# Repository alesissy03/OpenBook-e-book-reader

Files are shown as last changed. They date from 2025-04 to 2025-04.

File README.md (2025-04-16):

# OpenBook-e-book-reader



# Project Structure
```
OpenBook E-Reader
├── Hardware
│ ├── E-Reader.sch
│ └── E-Reader.brd
├── Manufacturing
│ ├── gerbers.zip
│ ├── bom.csv
│ └── pap.csv
├── Mechanical
│ ├── E-Reader.zip # STEP model archive
│ ├── E-Reader.f3z
│ └── OpenBook Enclosure.f3d # Enclosure model
├── Images
│ ├── 3d.png
│ ├── Schematic.png
│ ├── Board.png
│ └── Board_in_box.png
├── LICENSE # Apache 2.0
└── README.md
```

# Bill of Materials

## Component List

| Name | Description | Value | Quantity | Link to buy| Datasheet |
|---|---|---|---|---|---|
| 744043680 | IND_4828-WE-TPC_WRE | 68uH | 1 | https://mou.sr/42yVhMe | https://www.we-online.com/components/products/datasheet/744043680.pdf |
| 112A-TAAR-RO3_ATTEND | Micro SD Card Socket, Push-Push Type, Top Mount, SMT, H = 1.83mm | 10u | 1 | https://www.attend.com.tw/en/product.php?act=view&id=253# | https://www.attend.com.tw/data/download/file/112A-TAAR-R03_Spec.pdf |
| BD5229G-TR | Voltage Detector with Adjustable Delay Time (CMOS) | | 1 | https://mou.sr/421TSO9 | https://fscdn.rohm.com/en/products/databook/datasheet/ic/power/voltage_detector/bd52xxg-e.pdf |
| BUTTON_CUSYOMV1 | Momentary Switch (Pushbutton) – SPST – SMD, 4.6 x 2.8mm | | 3 | https://mou.sr/41Yc6zX | https://4donline.ihs.com/images/VipMasterIC/IC/PANA/PANA-S-A0000771493/PANA-S-A0000771493-1.pdf? hkey=CECEF36DEECDED6468708AAF2E19C0C6 |
| CPH3225A | Capacitor 0.011F 3.3V 1210 Flat | | 1 | https://mou.sr/42aoXOc | https://ro.mouser.com/datasheet/2/360/Seiko_Instruments_MicroBattery_E_20230330_2024Jan_-3561061.pdf |
| DS3231SN# | Real Time Clock Serial 16-Pin SOIC W T/R | | 1 | https://mou.sr/4ll9PXb | https://ro.mouser.com/datasheet/2/609/DS3231-3421123.pdf |
| EAGLE-LTSPICE_CC0402 | Capacitor | 100nF | 8 | https://mou.sr/42aprE0 | https://www.mouser.com/catalog/specsheets/Kemet_2-4-2024_KEM_F3140_R41D_Y2_300%20(draft3)%20(3).pdf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. |
| EAGLE-LTSPICE_CC0402 | Capacitor | 4.7uF | 5 | https://mou.sr/44lcHNw | https://ro.mouser.com/datasheet/2/40/AutoMLCCKAM-3216307.pdf |
| EAGLE-LTSPICE_CC0402 | Capacitor | 10uF | 1 | https://mou.sr/3G8LNhS | https://ro.mouser.com/datasheet/2/40/cx5r_KGM-3223198.pdf |
| EAGLE-LTSPICE_CC0402 | Capacitor | 1uF/50V | 9 | https://mou.sr/3YwHHGK | https://ro.mouser.com/datasheet/2/447/upy_gphc_x5r_4v_to_50v-3461255.pdf |
| EAGLE-LTSPICE_CC0402 | Capacitor | 0.1uF/50V | 1 | https://mou.sr/3RC3wkl | https://product.tdk.com/system/files/dam/doc/product/capacitor/ceramic/mlcc/catalog/mlcc_commercial_midvoltage_en.pdf |
| EAGLE-LTSPICE_CC0402 | Capacitor | 1nF | 1 | https://mou.sr/3YwHHGK | https://ro.mouser.com/datasheet/2/447/upy_gphc_x5r_4v_to_50v-3461255.pdf |
| ESP32_WROVER_BME680_BME680 | Integrated Environmental Unit (BME680) | | 1 | https://mou.sr/42kgEzJ | https://ro.mouser.com/datasheet/2/783/BST_BME680_DS001-1509608.pdf |
| ESP32_WROVER_AVX--- | Schotty Barrier Rectifier Diode | | 1 | |
| ESP32_WROVER_RR0402 | Resistor | 10k | 15 | https://mou.sr/4i5Vvim | https://www.vishay.com/docs/53046/pfrr.pdf |
| ESP32_WROVER_RR0402 | Resistor | 2.2 | 1 | https://mou.sr/4i9Xsun | https://www.vishay.com/docs/53046/pfrr.pdf |
| ESP32_WROVER_RR0402 | Resistor | 0.47 | 1 | https://mou.sr/4i9XAKn | https://www.vishay.com/docs/53046/pfrr.pdf |
| ESP32_WROVER_RR0402 | Resistor | 200 | 1 | https://mou.sr/4i9XAKn | https://www.vishay.com/docs/53046/pfrr.pdf |
| ESP32_WROVER_RR0402 | Resistor | 2k | 1 | https://mou.sr/4jeq8Do | https://www.vishay.com/docs/53046/pfrr.pdf |
| ESP32_WROVER_RR0402 | Resistor | 15 | 1 | https://mou.sr/4i5Vvim | https://www.vishay.com/docs/53046/pfrr.pdf |
| ESP32_WROVER_RR0402 | Resistor | 5k1 | 2 | https://mou.sr/4jeq8Do | https://www.vishay.com/docs/53046/pfrr.pdf |
| ESP32_WROVER_RR0402 | Resistor | 100k | 1 | https://mou.sr/4jeq8Do | https://www.vishay.com/docs/53046/pfrr.pdf |
| ESP32_WROVER_SPARKFUN- | P-channel MOSFETs | | 2 | https://mou.sr/42jyNxv | https://ro.mouser.com/datasheet/2/268/MCP73831_Family_Data_Sheet_DS20001984H-3441711.pdf |
| ESP32_WROVER_SPARKFUN-IC- | MCP73831T Li-Ion, Li-Pol Controller | | 1 | https://mou.sr/42jyNxv | https://ro.mouser.com/datasheet/2/268/MCP73831_Family_Data_Sheet_DS20001984H-3441711.pdf |
| ESP32C6_VARISTORCN1812 | Varistor | | 1 | https://mou.sr/3RnbVYV | https://www.tdk-electronics.tdk.com/inf/75/db/CTVS_14/Surge_protection_series.pdf |
| ESP32-C6-WROOM-1-N8 | | | 1 | https://mou.sr/42swLfH | https://ro.mouser.com/datasheet/2/891/Espressif_ESP32_C6_WROOM_1__Datasheet_V0_1_PRELIMI-3239987.pdf |
| FH34SRJ-24S-0.5SH_99_ | 24-pos FFC/FPC Connector, Right Angle | | 1 |  https://mou.sr/43Cr53R | https://ro.mouser.com/datasheet/2/185/FH34SRJ_24S_0_5SH_99__CL0580_1255_6_99_2DDrawing_0-1615044.pdf |
| MAX17048G+T10 | Fuel Gauge | | 1 | https://mou.sr/3FWR5wY | https://ro.mouser.com/datasheet/2/609/MAX17048_MAX17049-3469099.pdf |
| MBR0530 | Diode, Schottky, 0.5A, 30V, SOD-123 | | 2 | https://mou.sr/4jmza1b | https://www.onsemi.com/download/data-sheet/pdf/mbr0530t1-d.pdf |
| PGB1010603MR | ESD Suppressor | | 6 | https://mou.sr/3Yg9sDe | https://www.littelfuse.com/assetdocs/pulseguard-esd-suppressors-pgb1-datasheet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 |
| QWIIC_CONNECTORJS-1MM | I²C Standard Qwiic Connector | | 1 | https://www.sparkfun.com/qwiic-jst-connector-smd-4-pin-horizontal.html | https://cdn.sparkfun.com/assets/parts/1/2/2/8/9/Qwiic_Connector_Datasheet.pdf |
| RCL_CPOL-EUCT3528 | Polarized Capacitor (Tantalum) | 100uF TANT | 1 | https://mou.sr/42webCl | https://www.mouser.com/catalog/specsheets/Panasonic_08082018_Capacitor%20Radial%20Leaded%20Lytic%20(EEU-FS)%20020118.pdf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. |
| SAMACSYS_USB4110-GF-A | USB 2.0 Type-C Connector, Right Angle SMT | | 1 | https://www.digikey.ro/en/products/detail/gct/USB4110-GF-A/10384547 | https://gct.co/files/specs/usb4110-spec.pdf?v=6b2a6292-70a5-4bd5-a7e5-0f3fe03e015f |
| SI1308EDL-T1-GE3 | MOSFET N-Ch 30V 1.5A Vishay TrenchFET | | 1 | https://mou.sr/4lj7JXH | https://www.vishay.com/docs/63399/si1308edl.pdf |
| SJ | SMD Solder Jumper | | 1 | https://mou.sr/42luaTB | https://ro.mouser.com/datasheet/2/972/cjs-1827353.pdf |
| USBLC6-2SC6Y | ESD Protection Diode Array, 6-Pin SOT-23 | | 1 | https://mou.sr/42lyiTK | https://ro.mouser.com/datasheet/2/389/usblc6_2sc6y-1852505.pdf |
| W25Q512JVEIQ | Flash Memory | | 1 | https://mou.sr/42vsB6J | https://ro.mouser.com/datasheet/2/949/Winbond_W25Q512JV_Datasheet-3240039.pdf |
| XC6220A331MR-G | LDO Voltage Regulator | | 1 | https://mou.sr/4ieKgVa | https://ro.mouser.com/ProductDetail/Torex-Semiconductor/XC6220A331MR-G?qs=AsjdqWjXhJ8ZSWznL1J0gg%3D%3D |

# ESP32 C6

| Pin | Name | Label|  Function | Connection to  |
|---|---|---|---|---|
| 1 | GND | - | Ground | Ground |
| 2 | 3V3 | - | Power | 3.3V |
| 3 | EN | RESET |Reset | Pull-up to 3.3v |
| 4 | IO4 | SS_SD | SD card chip select | J4 |
| 5 | IO5 | EPD_DC | E-Paper Display Command | J4 |
| 6 | IO6 | SCK | SPI Clock | J3, J4 |
| 7 | IO7 | MOSI | Master Out Slave In | J3, J4 |
| 8 | IO0 | INT_RTC | RTC Interrupt | DS3231SN |
| 9 | IO1 | 32KHZ | 32 kHz output | DS3231SN |
| 10 | IO8 | - | Power | 3.3V |
| 11 | IO10 | EPD_CS | E-Paper Display Chip Select | J3 |
| 12 | IO11 | FLASH_CS | Exernal NOR Flash Chip Select | J4 |
| 13 | IO12 | USB_D- | USB D- | J2 via D2 |
| 14 | IO13 | USB_D+ | USB D+ | J2 via D2 |
| 15 | IO9 | IO/BOOT | BOOT button | BOOT button
| 16 | IO18 | RTC_RST | RTC Module Reset | DS3231SN |
| 17 | IO19 | I2C_PW | Power | BME688 Sensor |
| 18 | IO20 | EPD_3V3_C | E-Paper Display Power | 
| 19 | IO21 | SDA | Battery Level
| 20 | IO22 | SCL | Battery Level
| 21 | IO23 | EPD_RST | E-Paper Display Reset | J4
| 22 | NC | - | - | -
| 23 | IO15 | IO/CHANGE | Change button | Change Button
| 24 | RXD0/GPIO17 | RX | UART EX
| 25 | TXD0/GPIO16 | TX | UART TX
| 26 | IO3 | EPD_BUSY | E-Paper Display Busy signal | J4
| 27 | IO2 | MISO | Master In Slave Out | J3, J4 

# Errors and warnings
During the design process in Autodesk Fusion, several warnings were flagged in both the schematic and PCB layouts. Below is a summary of the warnings I reviewed and explicitly approved based on the context of this project:

## Schematic (only warnings, no errors)
### "POWER pin X connected to Y" Warnings
- VBAT is supplied via a battery circuit
- 3V3 is regulated by a dedicated LDO
- I2C_PW and other power rails are driven by appropriate sources
- All GND connections are correctly tied to a common ground plane
- POWER pin U3 VBAT connected to VRTC is intentional, VRTC is your battery backup supply for the RTC
- POWER pin SENSOR2 VDDIO connected to I2C_PW / POWER pin SENSOR2 VDD connected to I2C_PW: these refer to the BME680 sensor (SENSOR2), which uses VDD for logic and VDDIO for I/O voltage levels
- POWER pin MCP73831 VIN connected to VBUS: the MCP73831 is a Li-Ion battery charger, and VIN is supposed to be connected to a power input, like USB VBUS
### "Part X has no value" Warnings
- Those parts are supposed not to have value (for example the frame)

## Board
- Smd-Hole, Board Outline-Clearance error (at USB C connector): ok to approved as per instructions given
- Copper width errors (1 data wire, 3 power wires): approved because I manually checked the wire and it has the desired width

_Disclaimer: This project was done using Fusion in browser._

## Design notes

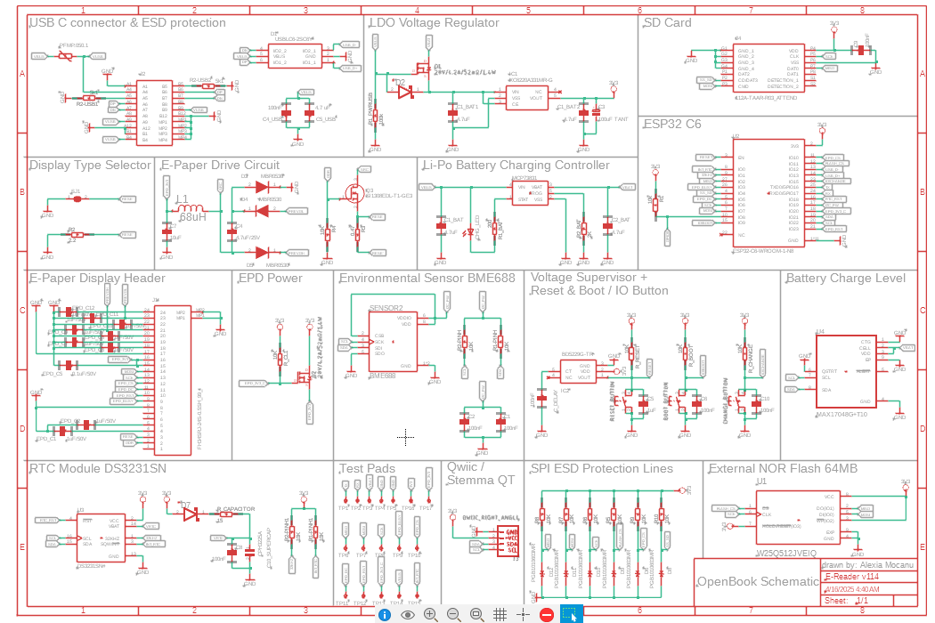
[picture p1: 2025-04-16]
Images/Schematic.png

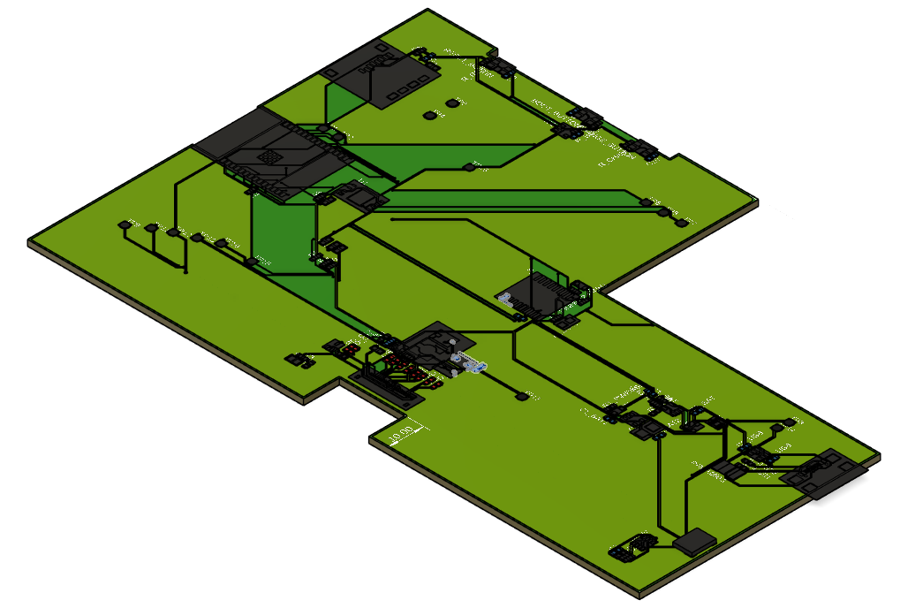
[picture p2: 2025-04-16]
Images/3D.png

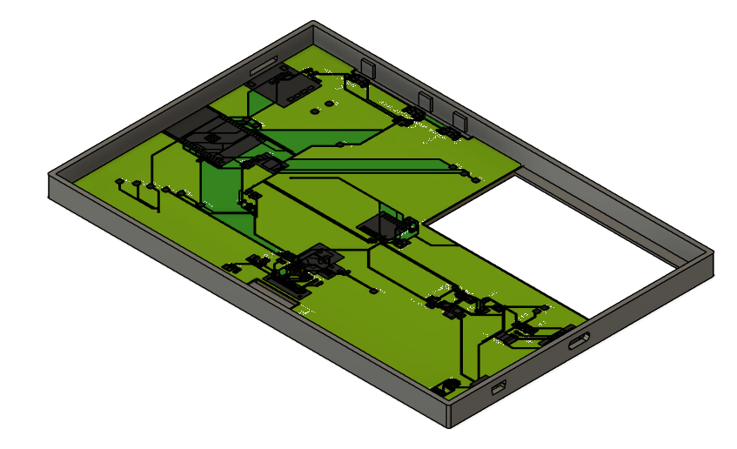
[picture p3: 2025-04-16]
Images/Board_in_box.png

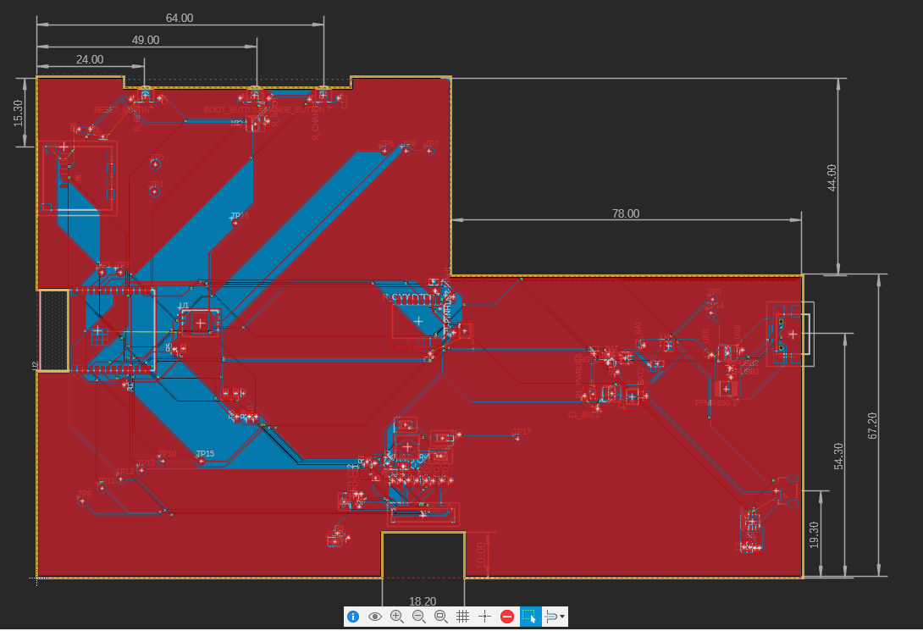
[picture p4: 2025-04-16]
Images/Board.png

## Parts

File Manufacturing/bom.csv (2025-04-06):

Qty | Value | Device | Package | Parts | Description | ARROW_PART_NUMBER | ARROW_PRICE-STOCK | AVAILABILITY | CENTROID_NOT_SPECIFIED | CHECK_PRICES | COPYRIGHT | DATASHEET | DESCRIPTION | DIGIKEY_DESCRIPTION | DIGIKEY_PART_NUMBER | HEIGHT | LEAD_FREE | MANUFACTURER_NAME | MANUFACTURER_PART_NUMBER | MF | MFR_NAME | MOUSER_PART_NUMBER | MOUSER_PRICE-STOCK | MOUSER_TESTING_PART_NUMBER | MOUSER_TESTING_PRICE-STOCK | MP | MPN | PACKAGE | POPULARITY | PREFIX | PRICE | PROD_ID | PURCHASE-URL | ROHS | SNAPEDA_LINK | SPICEMODEL | SPICEPREFIX | TEMPERATURE_RANGE_HIGH | TEMPERATURE_RANGE_LOW | TP_SIGNAL_NAME | VALUE
1 |  | ADAFRUIT_LEDCHIP-LED0603 | ADAFRUIT_CHIP-LED0603 | CHG_LED | LED
3 |  | BUTTON_CUSYOMV1 | MYBUTTON | BOOT_BUTTON, CHANGE_BUTTON, RESET_BUTTIN
1 |  | ESP32C6_VARISTORCN1812 | ESP32C6_VARISTOR_CT/CN1812 | PFMP.050.1 | VARISTOR |  |  |  |  |  |  |  |  |  |  |  |  |  |  |  |  |  |  |  |  |  |  |  | 0
1 |  | ESP32_WROVER_SPARKFUN-IC-POWER_MCP73831 | ESP32_WROVER_SPARKFUN-IC-POWER_SOT23-5 | MCP73831 | MCP73831T Li-Ion, Li-Pol Controller |  |  |  |  |  |  |  |  |  |  |  |  |  |  |  |  |  |  |  |  |  |  |  |  |  |  | IC-09995
1 |  | SAMACSYS_PARTS_USB4110-GF-A | SAMACSYS_PARTS_USB4110GFA | J2 | CONN USB 2.0 TYPE-C R/A SMT |  |  |  |  |  |  |  | CONN USB 2.0 TYPE-C R/A SMT |  |  | 3.26mm |  | GCT (GLOBAL CONNECTOR TECHNOLOGY) | USB4110-GF-A |  |  | 640-USB4110-GF-A | https://www.mouser.co.uk/ProductDetail/GCT/USB4110-GF-A?qs=KUoIvG%2F9IlYiZvIXQjyJeA%3D%3D
1 |  | SJ | SJ | SJ1 | SMD solder JUMPER |  |  |  |  |  |  |  |  |  |  |  |  |  |  |  |  |  |  |  |  |  |  |  | 3
1 | 0.1uF/50V | EAGLE-LTSPICE_CC0402 | EAGLE-LTSPICE_C0402 | EPD_C5 | CAPACITOR, European symbol |  |  |  |  |  |  |  |  |  |  |  |  |  |  |  |  |  |  |  |  |  |  |  |  |  |  |  |  |  |  | NONE | C
1 | 0.47 | ESP32_WROVER_EAGLE-LTSPICE_RR0402 | ESP32_WROVER_EAGLE-LTSPICE_R0402 | R3 | RESISTOR, European symbol |  |  |  |  |  |  |  |  |  |  |  |  |  |  |  |  |  |  |  |  |  |  |  |  |  |  |  |  |  |  | NONE | R
1 | 100k | ESP32_WROVER_EAGLE-LTSPICE_RR0402 | ESP32_WROVER_EAGLE-LTSPICE_R0402 | R1_PWRUSB | RESISTOR, European symbol |  |  |  |  |  |  |  |  |  |  |  |  |  |  |  |  |  |  |  |  |  |  |  |  |  |  |  |  |  |  | NONE | R
8 | 100nF | EAGLE-LTSPICE_CC0402 | EAGLE-LTSPICE_C0402 | C1, C2, C4_USB, C6, C8, C9, C10, C_DELAY | CAPACITOR, European symbol |  |  |  |  |  |  |  |  |  |  |  |  |  |  |  |  |  |  |  |  |  |  |  |  |  |  |  |  |  |  | NONE | C
1 | 100uF TANT | RCL_CPOL-EUCT3528 | RCL_CT3528 | C3 | POLARIZED CAPACITOR, European symbol |  |  |  |  |  |  |  |  |  |  |  |  |  |  |  |  |  |  |  |  |  |  |  | 0 |  |  |  |  |  |  |  | C
15 | 10K | ESP32_WROVER_EAGLE-LTSPICE_RR0402 | ESP32_WROVER_EAGLE-LTSPICE_R0402 | R1-PINH, R1-PINH1, R2-PINH, R2-PINH1, R4, R5, R6, R7, R8, R9, R10, R_BOOT, R_CHANGE, R_CL1, R_RESET | RESISTOR, European symbol |  |  |  |  |  |  |  |  |  |  |  |  |  |  |  |  |  |  |  |  |  |  |  |  |  |  |  |  |  |  | NONE | R
1 | 10k | ESP32_WROVER_EAGLE-LTSPICE_RR0402 | ESP32_WROVER_EAGLE-LTSPICE_R0402 | R1 | RESISTOR, European symbol |  |  |  |  |  |  |  |  |  |  |  |  |  |  |  |  |  |  |  |  |  |  |  |  |  |  |  |  |  |  | NONE | R
1 | 10uF | EAGLE-LTSPICE_CC0402 | EAGLE-LTSPICE_C0402 | C7 | CAPACITOR, European symbol |  |  |  |  |  |  |  |  |  |  |  |  |  |  |  |  |  |  |  |  |  |  |  |  |  |  |  |  |  |  | NONE | C
1 | 112A-TAAR-R03_ATTEND | 112A-TAAR-R03_ATTEND | 112ATAARR03ATTEND | J4 | Micro SD Card Socket, Push-Push Type, Top Mount, SMT, H=1.83mm, 10u |  |  |  |  |  |  |  | Micro SD Card Socket | Push-Push Type | Top Mount | SMT | H=1.83mm | 10u |  |  | 1.9mm |  | ATTEND | 112A-TAAR-R03 ATTEND
1 | 15 | ESP32_WROVER_EAGLE-LTSPICE_RR0402 | ESP32_WROVER_EAGLE-LTSPICE_R0402 | R_CAPACITOR | RESISTOR, European symbol |  |  |  |  |  |  |  |  |  |  |  |  |  |  |  |  |  |  |  |  |  |  |  |  |  |  |  |  |  |  | NONE | R
1 | 1uF | EAGLE-LTSPICE_CC0402 | EAGLE-LTSPICE_C0402 | C5 | CAPACITOR, European symbol |  |  |  |  |  |  |  |  |  |  |  |  |  |  |  |  |  |  |  |  |  |  |  |  |  |  |  |  |  |  | NONE | C
9 | 1uF/50V | EAGLE-LTSPICE_CC0402 | EAGLE-LTSPICE_C0402 | EPD_C1, EPD_C2, EPD_C6, EPD_C7, EPD_C8, EPD_C9, EPD_C10, EPD_C11, EPD_C12 | CAPACITOR, European symbol |  |  |  |  |  |  |  |  |  |  |  |  |  |  |  |  |  |  |  |  |  |  |  |  |  |  |  |  |  |  | NONE | C
1 | 2.2 | ESP32_WROVER_EAGLE-LTSPICE_RR0402 | ESP32_WROVER_EAGLE-LTSPICE_R0402 | R2 | RESISTOR, European symbol |  |  |  |  |  |  |  |  |  |  |  |  |  |  |  |  |  |  |  |  |  |  |  |  |  |  |  |  |  |  | NONE | R
1 | 200 | ESP32_WROVER_EAGLE-LTSPICE_RR0402 | ESP32_WROVER_EAGLE-LTSPICE_R0402 | R1_BAT | RESISTOR, European symbol |  |  |  |  |  |  |  |  |  |  |  |  |  |  |  |  |  |  |  |  |  |  |  |  |  |  |  |  |  |  | NONE | R
1 | 20V/4.2A/52mO/1.4W | ESP32_WROVER_SPARKFUN-DISCRETESEMI_MOSFET_PCH-DMG2305UX-7 | ESP32_WROVER_SPARKFUN-DISCRETESEMI_SOT23-3 | Q1 | P-channel MOSFETs |  |  |  |  |  |  |  |  |  |  |  |  |  |  |  |  |  |  |  |  |  |  |  |  |  |  | TRAN-14388 |  |  |  |  |  |  |  |  | 20V/4.2A/52mO/1.4W
1 | 20V/4.2A/52mO/1.4W | ESP32_WROVER_SPARKFUN-DISCRETESEMI_MOSFET_PCH-DMG2305UX-7 | ESP32_WROVER_SPARKFUN-DISCRETESEMI_SOT23-3 | Q2 | P-channel MOSFETs |  |  |  |  |  |  |  |  |  |  |  |  |  |  |  |  |  |  |  |  |  |  |  |  |  |  | TRAN-14388 |  |  |  |  | Q |  |  |  | 20V/4.2A/52mO/1.4W
1 | 2K | ESP32_WROVER_EAGLE-LTSPICE_RR0402 | ESP32_WROVER_EAGLE-LTSPICE_R0402 | R2_BAT | RESISTOR, European symbol |  |  |  |  |  |  |  |  |  |  |  |  |  |  |  |  |  |  |  |  |  |  |  |  |  |  |  |  |  |  | NONE | R
1 | 4.7 uF | EAGLE-LTSPICE_CC0402 | EAGLE-LTSPICE_C0402 | C5_USB | CAPACITOR, European symbol |  |  |  |  |  |  |  |  |  |  |  |  |  |  |  |  |  |  |  |  |  |  |  |  |  |  |  |  |  |  | NONE | C
4 | 4.7uF | EAGLE-LTSPICE_CC0402 | EAGLE-LTSPICE_C0402 | C1_BAT, C1_BAT1, C1_BAT2, C2_BAT | CAPACITOR, European symbol |  |  |  |  |  |  |  |  |  |  |  |  |  |  |  |  |  |  |  |  |  |  |  |  |  |  |  |  |  |  | NONE | C
1 | 4.7uF/25V | EAGLE-LTSPICE_CC0402 | EAGLE-LTSPICE_C0402 | C4 | CAPACITOR, European symbol |  |  |  |  |  |  |  |  |  |  |  |  |  |  |  |  |  |  |  |  |  |  |  |  |  |  |  |  |  |  | NONE | C
2 | 5k1 | ESP32_WROVER_EAGLE-LTSPICE_RR0402 | ESP32_WROVER_EAGLE-LTSPICE_R0402 | R2-USB1, R2-USB2 | RESISTOR, European symbol |  |  |  |  |  |  |  |  |  |  |  |  |  |  |  |  |  |  |  |  |  |  |  |  |  |  |  |  |  |  | NONE | R
1 | 68uH | 744043680IND_4828-WE-TPC_WRE | IND_4828-WE-TPC_WRE | L1 |  |  |  |  |  |  | Copyright (C) 2024 Ultra Librarian. All rights reserved. |  |  |  |  |  |  |  | 744043680 |  | Wurth Electronics
1 | BD5229G-TR | BD5229G-TR | SOT95P280X125-5N | IC2 | Voltage Detector with Adjustable Delay Time: CMOS processes are utilized to develop high precision, low current consumption CMOS reset ICs that allow arbitrary setting of the delay time. The extensive lineup includes both Nch Open Drain and CMOS output types in a wide range of detection voltages (from 2.3V to 6.0V, in 0.1V steps), enabling selection of the ideal solution based on customer requirements. In addition, the entire series is of course both lead-free and RoHS-compliant. |  |  |  |  |  |  |  | Voltage Detector with Adjustable Delay Time: CMOS processes are utilized to develop high precision | low current consumption CMOS reset ICs that allow arbitrary setting of the delay time. The extensive lineup includes both Nch Open Drain and CMOS output types in a wide range of detection voltages (from 2.3V to 6.0V | in 0.1V steps) | enabling selection of the ideal solution based on customer requirements. In addition | the entire series is of course both lead-free and RoHS-compliant. |  |  | 1.25mm |  | ROHM Semiconductor | BD5229G-TR |  |  | 755-BD5229G-TR | https://www.mouser.co.uk/ProductDetail/ROHM-Semiconductor/BD5229G-TR?qs=4kLU8WoGk0vvnhrrYwdszw%3D%3D
1 | BME688 | ESP32_WROVER_BME680_BME680 | ESP32_WROVER_BME680_PSON80P300X300X100-8N | SENSOR2 | Integrated Environmental Unit |  |  | Unavailable |  |  |  |  | Integrated Environmental Unit |  |  |  |  |  |  | Bosch Sensortec |  |  |  |  |  | BME680 |  | LGA-8 Bosch Tools |  |  | None
1 | CPH3225A | CPH3225A | CAPCP3225X100N | C10_SUPERCAP | Cap 0.011F 3.3V 1210 Flat Check availability |  |  | Not in stock |  | https://www.snapeda.com/parts/CPH3225A/Seiko+Instruments/view-part/?ref=eda |  |  | 11 mF (EDLC) Supercapacitor 3.3 V 1210 (3225 Metric) - - |  |  |  |  |  |  | Seiko Instruments |  |  |  |  |  | CPH3225A |  | 1210 Seiko |  |  | None |  | https://www.snapeda.com/api/url_track_click_mouser/?unipart_id=562593&manufacturer=Seiko Instruments&part_name=CPH3225A&search_term=None |  | https://www.snapeda.com/parts/CPH3225A/Seiko+Instruments/view-part/?ref=snap
1 | DS3231SN# | DS3231SN# | SOIC127P1032X265-16N | U3 | Real Time Clock Serial 16-Pin SOIC W T/R Check availability |  |  | In Stock |  | https://www.snapeda.com/parts/DS3231SN%23/Analog+Devices/view-part/?ref=eda |  |  | Extremely Accurate I²C-Integrated RTC/TCXO/Crystal |  |  |  |  |  |  | Analog Devices |  |  |  |  |  | DS3231SN# |  | SOIC-16 Maxim |  |  | None |  | https://www.snapeda.com/api/url_track_click_mouser/?unipart_id=99048&manufacturer=Analog Devices&part_name=DS3231SN#&search_term=None |  | https://www.snapeda.com/parts/DS3231SN%23/Analog+Devices/view-part/?ref=snap
1 | ESP32-C6-WROOM-1-N8 | ESP32-C6-WROOM-1-N8 | XCVR_ESP32-C6-WROOM-1-N8 | U2 | Check availability |  |  | In Stock |  | https://www.snapeda.com/parts/ESP32-C6-WROOM-1-N8/Espressif+Systems/view-part/?ref=eda |  |  | Multiprotocol Modules ESP32-C6 module | Wi-Fi 6 in 2.4 GHz band | Bluetooth 5 | Zigbee 3.0 and Thread. ESP34-WROOM Compatible - ENGINEERING SAMPLE |  |  |  |  |  |  | Espressif Systems |  |  |  |  |  | ESP32-C6-WROOM-1-N8 |  | None |  |  | None |  |  |  | https://www.snapeda.com/parts/ESP32-C6-WROOM-1-N8/Espressif+Systems/view-part/?ref=snap
1 | ESP32_WROVER_AVX---SD0805S020S1R0_AVX_SD0805S020S1R0_0_0AVX_SD0805S020S1R0_0_0 | ESP32_WROVER_AVX---SD0805S020S1R0_AVX_SD0805S020S1R0_0_0AVX_SD0805S020S1R0_0_0 | ESP32_WROVER_AVX---SD0805S020S1R0_AVX_SD0805S020S1R0_0 | D2 | Schottky Barrier Rectifier Diode |  |  |  | No |  |  | http://datasheets.avx.com/schottky.pdf |  | DIODE SCHOTTKY 20V 1A 0805 | 478-7800-1-ND |  | yes |  |  | AVX |  | 581-SD0805S020S1R0 |  |  |  |  |  | 0805 (2012 metric) |  | D |  |  |  | yes |  |  |  | +125°C | -55°C
1 | FH34SRJ-24S-0.5SH_99_ | FH34SRJ-24S-0.5SH_99_ | FH34SRJ24S05SH99 | J1 | (0.50mm) Surface Mount, Right Angle |  |  |  |  |  |  |  | 24 Position FFC | FPC Connector Contacts | (0.50mm) Surface Mount | Right Angle |  |  | 1.1mm |  | Hirose | FH34SRJ-24S-0.5SH(99) |  |  | 798-FH34SRJ24S05SH99 | https://www.mouser.co.uk/ProductDetail/Hirose-Connector/FH34SRJ-24S-0.5SH99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
1 | MAX17048G+T10 | MAX17048G+T10 | SON50P200X200X80-9N | U4 | Check availability |  |  | In Stock |  | https://www.snapeda.com/parts/MAX17048G+T10/Analog+Devices/view-part/?ref=eda |  |  | 3µA 1-Cell/2-Cell Fuel Gauge with ModelGauge |  |  |  |  |  |  | Analog Devices |  |  |  |  |  | MAX17048G+T10 |  | TDFN-8 Maxim |  |  | None |  | https://www.snapeda.com/api/url_track_click_mouser/?unipart_id=329239&manufacturer=Analog Devices&part_name=MAX17048G+T10&search_term=None |  | https://www.snapeda.com/parts/MAX17048G+T10/Analog+Devices/view-part/?ref=snap
3 | MBR0530 | MBR0530 | SOD3716X135N | D3, D4, D5 | ON SEMICONDUCTOR - MBR0530 - DIODE, SCHOTTKY, 0.5A, 30V, SOD-123 |  |  | In Stock |  | https://www.snapeda.com/parts/MBR0530/Onsemi/view-part/?ref=eda |  |  | Diode Schottky 30 V 500mA Surface Mount SOD-123 |  |  |  |  |  |  | ON Semiconductor |  |  |  |  |  | MBR0530 |  | SOD-123-2 ON Semiconductor |  |  | None |  | https://www.snapeda.com/api/url_track_click_mouser/?unipart_id=179458&manufacturer=ON Semiconductor&part_name=MBR0530&search_term=None |  | https://www.snapeda.com/parts/MBR0530/Onsemi/view-part/?ref=snap
6 | PGB1010603MR | PGB1010603MR | DIOC1608X36N | D6, D8, D9, D10, D11, D12 | Check availability |  |  | In Stock |  | https://www.snapeda.com/parts/PGB1010603MR/Littelfuse/view-part/?ref=eda |  |  | 150V (Typ) Clamp - Ipp Tvs Diode Surface Mount 0603 (1608 Metric) |  |  |  |  |  |  | Littelfuse Inc. |  |  |  |  |  | PGB1010603MR |  | 0603 Littelfuse Inc. |  |  | None |  | https://www.snapeda.com/api/url_track_click_mouser/?unipart_id=5659453&manufacturer=Littelfuse Inc.&part_name=PGB1010603MR&search_term=None |  | https://www.snapeda.com/parts/PGB1010603MR/Littelfuse/view-part/?ref=snap
1 | QWIIC_RIGHT_ANGLE | QWIIC_CONNECTORJS-1MM | JST04_1MM_RA | J3 | SparkFun I2C Standard Qwiic Connector |  |  |  |  |  |  |  |  |  |  |  |  |  |  |  |  |  |  |  |  |  |  |  |  |  |  | CONN-13694 |  |  |  |  |  |  |  |  | QWIIC_RIGHT_ANGLE
1 | SD0805S020S1R0 | ESP32_WROVER_AVX---SD0805S020S1R0_AVX_SD0805S020S1R0_0_0AVX_SD0805S020S1R0_0_0 | ESP32_WROVER_AVX---SD0805S020S1R0_AVX_SD0805S020S1R0_0 | D7 | Schottky Barrier Rectifier Diode |  |  |  | No |  |  | http://datasheets.avx.com/schottky.pdf |  | DIODE SCHOTTKY 20V 1A 0805 | 478-7800-1-ND |  | yes |  |  | AVX |  | 581-SD0805S020S1R0 |  |  |  |  |  | 0805 (2012 metric) |  | D |  |  |  | yes |  |  |  | +125°C | -55°C
1 | SI1308EDL-T1-GE3 | SI1308EDL-T1-GE3 | SOT65P210X110-3N | Q3 | MOSFET N-Ch 30V 1.5A TrenchFET SC70 Vishay Si1308EDL-T1-GE3 N-channel MOSFET Transistor, 1.5 A, 30 V, 3-Pin SC-70 |  |  | In Stock |  | https://www.snapeda.com/parts/SI1308EDL-T1-GE3/Vishay+Siliconix/view-part/?ref=eda |  |  | Si1308EDL-T1-GE3 N-channel MOSFET Transistor | 1.5 A | 30 V | 3-Pin SC-70 | Siliconix / Vishay SI1308EDL-T1-GE3 |  |  |  |  |  |  | Vishay Siliconix |  |  |  |  |  | SI1308EDL-T1-GE3 |  | SOT-323 Vishay Semiconductor |  |  | None |  | https://www.snapeda.com/api/url_track_click_mouser/?unipart_id=274603&manufacturer=Vishay Siliconix&part_name=SI1308EDL-T1-GE3&search_term=None |  | https://www.snapeda.com/parts/SI1308EDL-T1-GE3/Vishay+Siliconix/view-part/?ref=snap
17 | TPTP20R | TPTP20R | TP20R | TP1, TP2, TP3, TP4, TP5, TP6, TP7, TP8, TP9, TP10, TP11, TP12, TP13, TP14, TP15, TP16, TP17 | Test pad |  |  |  |  |  |  |  |  |  |  |  |  |  |  |  |  |  |  |  |  |  |  |  | 2
1 | USBLC6-2SC6Y | USBLC6-2SC6Y | SOT95P280X145-6N | D1 | Low Cap. ESD Protection Auto SOT-23-6 STMicroelectronics USBLC6-2SC6Y, Dual Uni-Directional TVS Diode Array, 6-Pin SOT-23 |  |  | In Stock |  | https://www.snapeda.com/parts/USBLC6-2SC6Y/STMicroelectronics/view-part/?ref=eda |  |  | 17V Clamp 5A (8/20µs) Ipp Tvs Diode Surface Mount SOT-23-6 |  |  |  |  |  |  | STMicroelectronics |  |  |  |  |  | USBLC6-2SC6Y |  | SOT-23-6 STMicroelectronics |  |  | None |  |  |  | https://www.snapeda.com/parts/USBLC6-2SC6Y/STMicroelectronics/view-part/?ref=snap
1 | W25Q512JVEIQ | W25Q512JVEIQ | SON127P600X800X80-9N | U1 | Check availability |  |  | In Stock |  | https://www.snapeda.com/parts/W25Q512JVEIQ/Winbond+Electronics/view-part/?ref=eda |  |  | FLASH - NOR Memory IC 512Mb (64M x 8) SPI - Quad I/O 133 MHz 8-WSON (8x6) |  |  |  |  |  |  | Winbond Electronics |  |  |  |  |  | W25Q512JVEIQ |  | Package |  |  | None |  |  |  | https://www.snapeda.com/parts/W25Q512JVEIQ/Winbond+Electronics/view-part/?ref=snap
1 | XC6220A331MR-G | XC6220A331MR-G | SOT95P280X120-5N | IC1 | LDO Voltage Regulators |  |  |  |  |  |  |  | LDO Voltage Regulators |  |  | 1.2mm |  | Torex | XC6220A331MR-G |  |  | 865-XC6220A331MR-G | https://www.mouser.co.uk/ProductDetail/Torex-Semiconductor/XC6220A331MR-G?qs=AsjdqWjXhJ8ZSWznL1J0gg%3D%3D

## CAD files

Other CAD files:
Mechanical/OpenBook Enclosure.f3d

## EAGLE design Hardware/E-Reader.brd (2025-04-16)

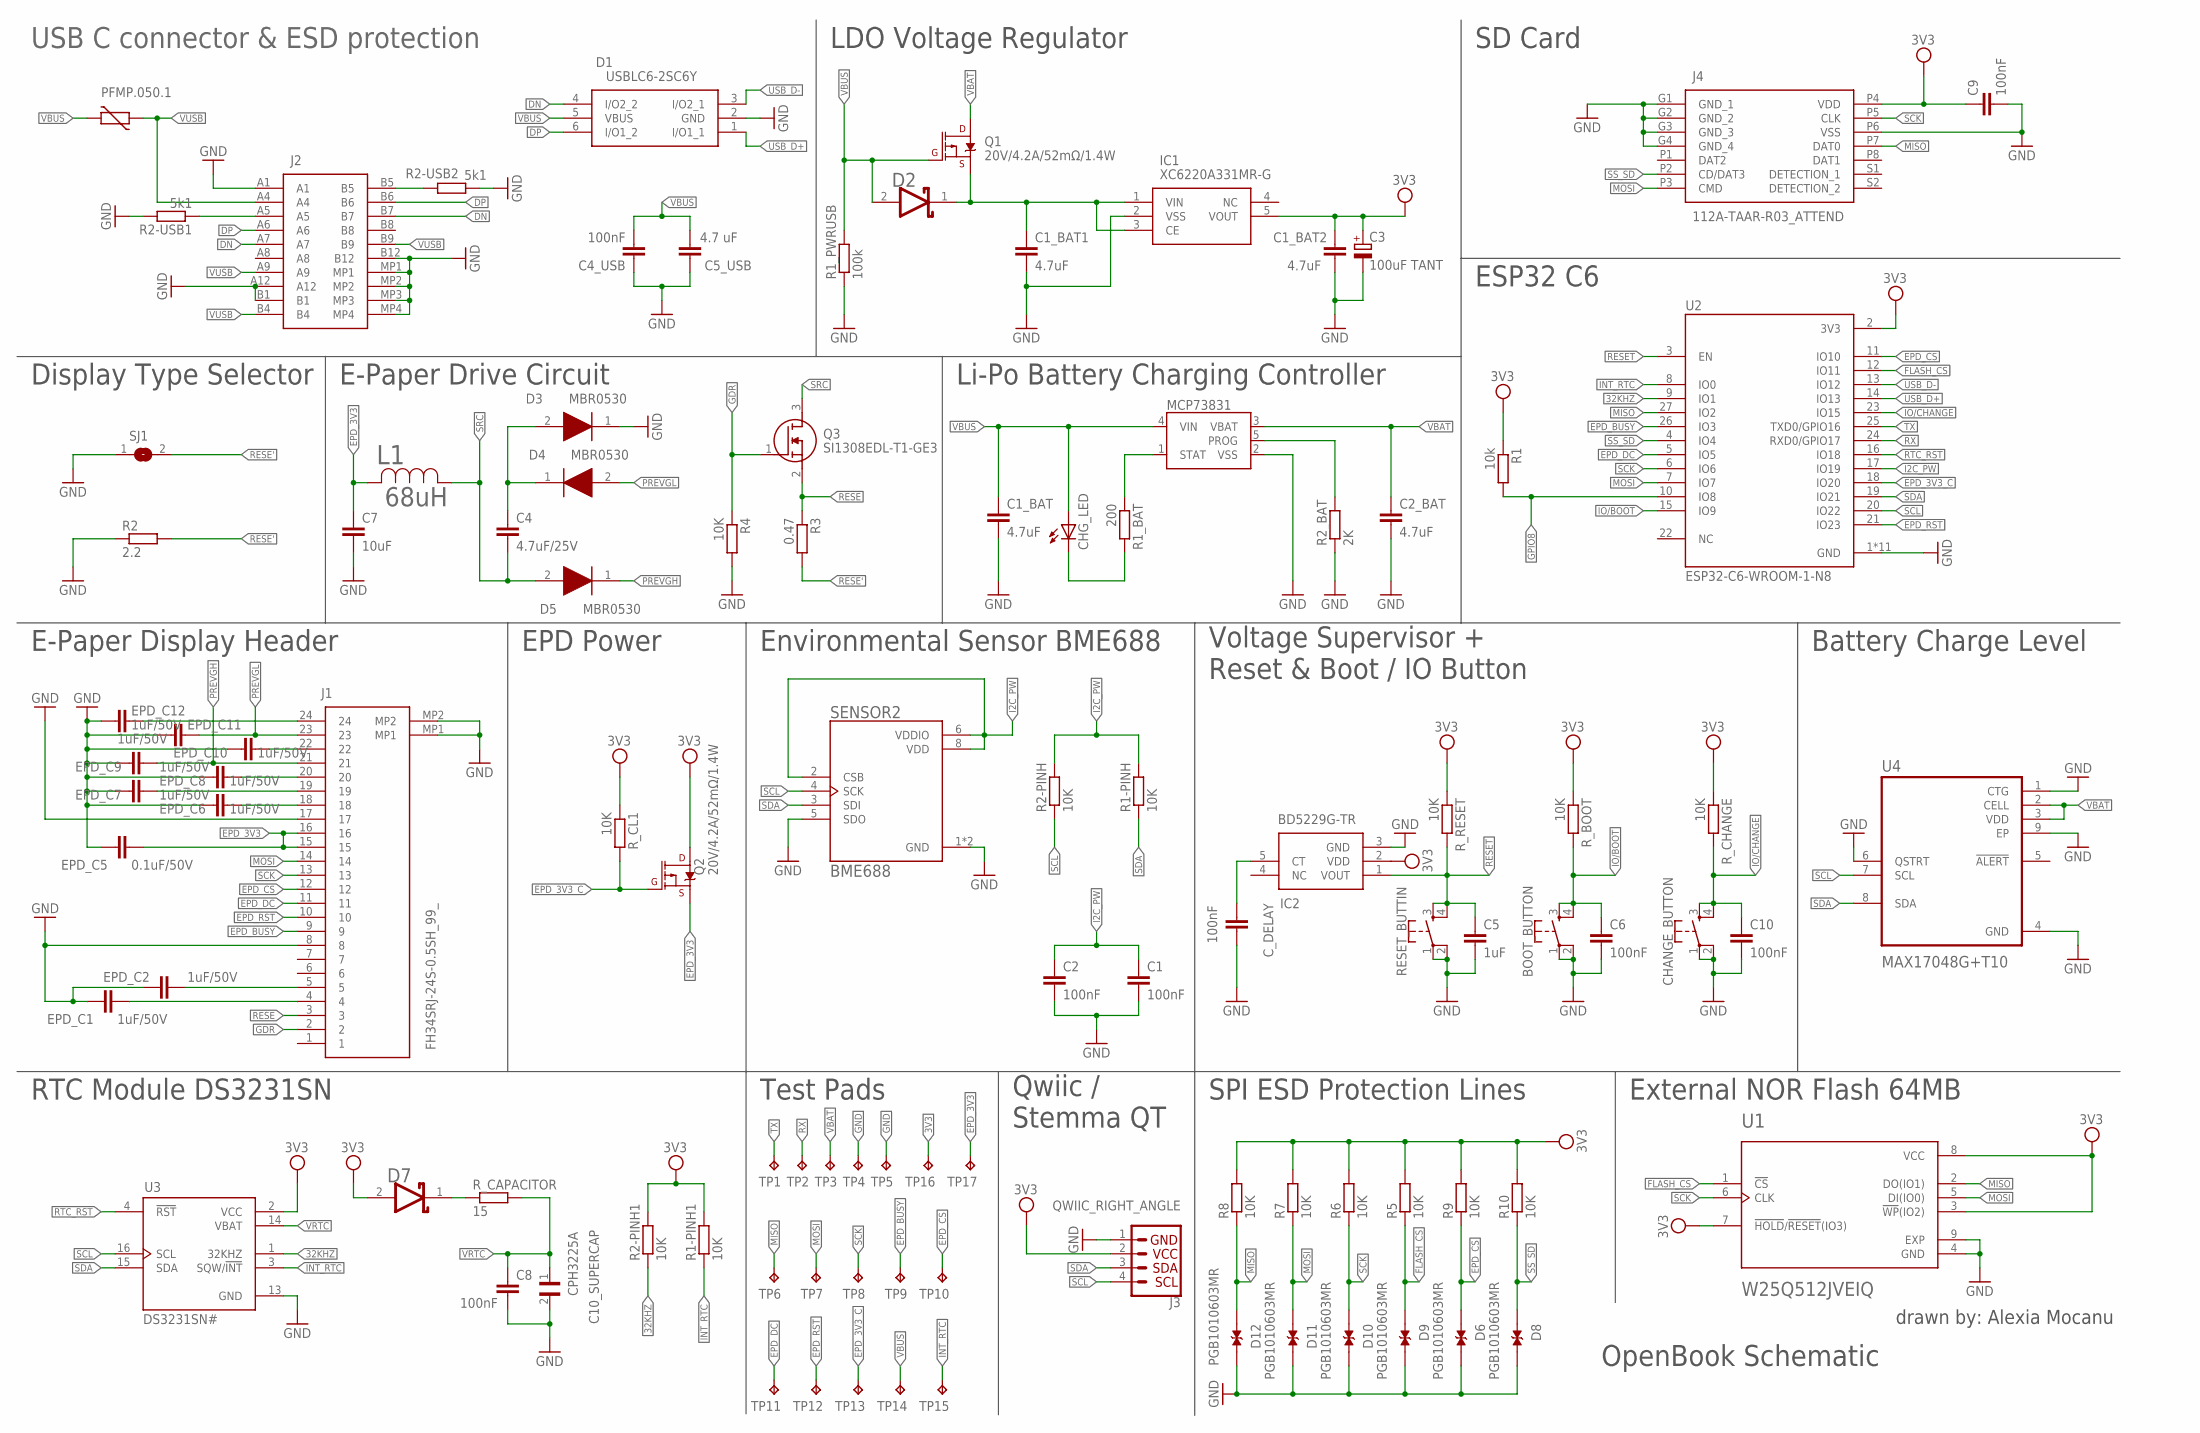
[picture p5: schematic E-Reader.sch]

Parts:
BOOT_BUTTON: BUTTON_CUSYOMV1; MYBUTTON
C1, C2, C4_USB, C6, C8, C9, C10: 100nF; EAGLE-LTSPICE_C0402
C1_BAT, C1_BAT1, C1_BAT2, C2_BAT: 4.7uF; EAGLE-LTSPICE_C0402
C3: 100uF TANT; RCL_CT3528
C4: 4.7uF/25V; EAGLE-LTSPICE_C0402
C5: 1uF; EAGLE-LTSPICE_C0402
C5_USB: 4.7 uF; EAGLE-LTSPICE_C0402
C7: 10uF; EAGLE-LTSPICE_C0402
C10_SUPERCAP: CPH3225A; CAPCP3225X100N
CHANGE_BUTTON: BUTTON_CUSYOMV1; MYBUTTON
CHG_LED: ADAFRUIT_LEDCHIP-LED0603; ADAFRUIT_CHIP-LED0603
C_DELAY: 100nF; EAGLE-LTSPICE_C0402
D1: USBLC6-2SC6Y; SOT95P280X145-6N
D2: ESP32_WROVER_AVX---SD0805S020S1R0_AVX_SD0805S020S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; ESP32_WROVER_AVX---SD0805S020S1R0_AVX_SD0805S020S1R0_0
D3, D4, D5: MBR0530; SOD3716X135N
D6, D8, D9, D10, D11, D12: PGB1010603MR; DIOC1608X36N
D7: SD0805S020S1R0; ESP32_WROVER_AVX---SD0805S020S1R0_AVX_SD0805S020S1R0_0
EPD_C1, EPD_C2, EPD_C6, EPD_C7, EPD_C8, EPD_C9, EPD_C10, EPD_C11, EPD_C12: 1uF/50V; EAGLE-LTSPICE_C0402
EPD_C5: 0.1uF/50V; EAGLE-LTSPICE_C0402
IC1: XC6220A331MR-G; SOT95P280X120-5N
IC2: BD5229G-TR; SOT95P280X125-5N
J1: FH34SRJ-24S-0.5SH_99_; FH34SRJ24S05SH99
J2: SAMACSYS_PARTS_USB4110-GF-A; SAMACSYS_PARTS_USB4110GFA
J3: QWIIC_RIGHT_ANGLE; JST04_1MM_RA
J4: 112A-TAAR-R03_ATTEND; 112ATAARR03ATTEND
L1: 68uH; IND_4828-WE-TPC_WRE
MCP73831: ESP32_WROVER_SPARKFUN-IC-POWER_MCP73831; ESP32_WROVER_SPARKFUN-IC-POWER_SOT23-5
PFMP.050.1: ESP32C6_VARISTORCN1812; ESP32C6_VARISTOR_CT/CN1812
Q1, Q2: 20V/4.2A/52mΩ/1.4W; ESP32_WROVER_SPARKFUN-DISCRETESEMI_SOT23-3
Q3: SI1308EDL-T1-GE3; SOT65P210X110-3N
R1: 10k; ESP32_WROVER_EAGLE-LTSPICE_R0402
R1-PINH, R1-PINH1, R2-PINH, R2-PINH1, R4, R5, R6, R7, R8, R9, R10: 10K; ESP32_WROVER_EAGLE-LTSPICE_R0402
R1_BAT: 200; ESP32_WROVER_EAGLE-LTSPICE_R0402
R1_PWRUSB: 100k; ESP32_WROVER_EAGLE-LTSPICE_R0402
R2: 2.2; ESP32_WROVER_EAGLE-LTSPICE_R0402
R2-USB1, R2-USB2: 5k1; ESP32_WROVER_EAGLE-LTSPICE_R0402
R2_BAT: 2K; ESP32_WROVER_EAGLE-LTSPICE_R0402
R3: 0.47; ESP32_WROVER_EAGLE-LTSPICE_R0402
RESET_BUTTIN: BUTTON_CUSYOMV1; MYBUTTON
R_BOOT: 10K; ESP32_WROVER_EAGLE-LTSPICE_R0402
R_CAPACITOR: 15; ESP32_WROVER_EAGLE-LTSPICE_R0402
R_CHANGE: 10K; ESP32_WROVER_EAGLE-LTSPICE_R0402
R_CL1: 10K; ESP32_WROVER_EAGLE-LTSPICE_R0402
R_RESET: 10K; ESP32_WROVER_EAGLE-LTSPICE_R0402
SENSOR2: BME688; ESP32_WROVER_BME680_PSON80P300X300X100-8N
SJ1: SJ
TP1, TP2, TP3, TP4, TP5, TP6, TP7, TP8, TP9, TP10, TP11, TP12, TP13, TP14, TP15, TP16, TP17: TPTP20R; TP20R
U1: W25Q512JVEIQ; SON127P600X800X80-9N
U2: ESP32-C6-WROOM-1-N8; XCVR_ESP32-C6-WROOM-1-N8
U3: DS3231SN#; SOIC127P1032X265-16N
U4: MAX17048G+T10; SON50P200X200X80-9N

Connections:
3V3: C1_BAT2.1, C3.+, C9.1, D7.2 (ANODE), IC1.5 (VOUT), IC2.2 (VDD), J3.2, J4.P4 (VDD), Q2.3 (D), R1.1, R1-PINH1.2, R2-PINH1.2, R5.2, R6.2, R7.2, R8.2, R9.2, R10.2, R_BOOT.1, R_CHANGE.1, R_CL1.1, R_RESET.1, TP16.TP, U1.3 (!WP!(IO2)), U1.7 (!HOLD!/!RESET!(IO3)), U1.8 (VCC), U2.2 (3V3), U3.2 (VCC)
32KHZ: R2-PINH1.1, U2.9 (IO1), U3.1 (32KHZ)
DN: D1.4 (I/O2_2), J2.A7, J2.B7
DP: D1.6 (I/O1_2), J2.A6, J2.B6
EPD_3V3: C7.1, EPD_C5.1, J1.15, J1.16, L1.2, Q2.2 (S), TP17.TP
EPD_3V3_C: Q2.1 (G), R_CL1.2, TP13.TP, U2.18 (IO20)
EPD_BUSY: J1.9, TP9.TP, U2.26 (IO3)
EPD_CS: D6.1, J1.12, R9.1, TP10.TP, U2.11 (IO10)
EPD_DC: J1.11, TP11.TP, U2.5 (IO5)
EPD_RST: J1.10, TP12.TP, U2.21 (IO23)
FLASH_CS: D9.1, R5.1, U1.1 (!CS), U2.12 (IO11)
GDR: J1.2, Q3.1 (G), R4.1
GND: BOOT_BUTTON.1, BOOT_BUTTON.2, C1.2, C1_BAT.2, C1_BAT1.2, C1_BAT2.2, C2.2, C2_BAT.2, C3.-, C4_USB.1, C5.2, C5_USB.1, C6.2, C7.2, C8.2, C9.2, C10.2, C10_SUPERCAP.2, CHANGE_BUTTON.1, CHANGE_BUTTON.2, C_DELAY.2, D1.2 (GND), D3.1 (K), D6.2, D8.2, D9.2, D10.2, D11.2, D12.2, EPD_C1.2, EPD_C2.2, EPD_C5.2, EPD_C6.2, EPD_C7.2, EPD_C8.2, EPD_C9.2, EPD_C10.2, EPD_C11.2, EPD_C12.2, IC1.2 (VSS), IC2.3 (GND), J1.8, J1.17, J1.MP1, J1.MP2, J2.A1, J2.A12, J2.B1, J2.B12, J2.MP1, J2.MP2, J2.MP3, J2.MP4, J3.1, J4.G1 (GND_1), J4.G2 (GND_2), J4.G3 (GND_3), J4.G4 (GND_4), J4.P6 (VSS), MCP73831.2 (VSS), R1_PWRUSB.1, R2.1, R2-USB1.2, R2-USB2.1, R2_BAT.1, R4.2, RESET_BUTTIN.1, RESET_BUTTIN.2, SENSOR2.1 (GND), SENSOR2.5 (SDO), SENSOR2.7 (GND), SJ1.1, TP4.TP, TP5.TP, U1.4 (GND), U1.9 (EXP), U2.1 (GND), U2.28 (GND), U2.29_1 (GND), U2.29_2 (GND), U2.29_3 (GND), U2.29_4 (GND), U2.29_5 (GND), U2.29_6 (GND), U2.29_7 (GND), U2.29_8 (GND), U2.29_9 (GND), U3.13 (GND), U4.1 (CTG), U4.4 (GND), U4.6 (QSTRT), U4.9 (EP)
GPIO8: R1.2, U2.10 (IO8)
I2C_PW: C1.1, C2.1, R1-PINH.2, R2-PINH.2, SENSOR2.2 (CSB), SENSOR2.6 (VDDIO), SENSOR2.8 (VDD), U2.17 (IO19)
INT_RTC: R1-PINH1.1, TP15.TP, U2.8 (IO0), U3.3 (SQW/!INT)
IO/BOOT: BOOT_BUTTON.3, BOOT_BUTTON.4, C6.1, R_BOOT.2, U2.15 (IO9)
IO/CHANGE: C10.1, CHANGE_BUTTON.3, CHANGE_BUTTON.4, R_CHANGE.2, U2.23 (IO15)
MISO: D12.1, J4.P7 (DAT0), R8.1, TP6.TP, U1.2 (DO(IO1)), U2.27 (IO2)
MOSI: D11.1, J1.14, J4.P3 (CMD), R7.1, TP7.TP, U1.5 (DI(IO0)), U2.7 (IO7)
unnamed: C1_BAT1.1, D2.1 (CATHODE), IC1.1 (VIN), IC1.3 (CE), Q1.2 (S)
unnamed: J2.A5, R2-USB1.1
unnamed: EPD_C12.1, J1.24
unnamed: C_DELAY.1, IC2.5 (CT)
unnamed: C4.1, D3.2 (A), D4.1 (K)
unnamed: MCP73831.1 (STAT), R1_BAT.1
unnamed: CHG_LED.C, R1_BAT.2
unnamed: J2.B5, R2-USB2.2
unnamed: MCP73831.5 (PROG), R2_BAT.2
unnamed: EPD_C10.1, J1.22
unnamed: EPD_C8.1, J1.20
unnamed: EPD_C7.1, J1.19
unnamed: EPD_C6.1, J1.18
unnamed: EPD_C1.1, J1.4
unnamed: EPD_C2.1, J1.5
unnamed: D7.1 (CATHODE), R_CAPACITOR.1
PREVGH: D5.1 (K), EPD_C9.1, J1.21
PREVGL: D4.2 (A), EPD_C11.1, J1.23
RESE: J1.3, Q3.2 (S), R3.1
RESE': R2.2, R3.2, SJ1.2
RESET: C5.1, IC2.1 (VOUT), RESET_BUTTIN.3, RESET_BUTTIN.4, R_RESET.2, U2.3 (EN)
RTC_RST: U2.16 (IO18), U3.4 (!RST)
RX: TP2.TP, U2.24 (RXD0/GPIO17)
SCK: D10.1, J1.13, J4.P5 (CLK), R6.1, TP8.TP, U1.6 (CLK), U2.6 (IO6)
SCL: J3.4, R2-PINH.1, SENSOR2.4 (SCK), U2.20 (IO22), U3.16 (SCL), U4.7 (SCL)
SDA: J3.3, R1-PINH.1, SENSOR2.3 (SDI), U2.19 (IO21), U3.15 (SDA), U4.8 (SDA)
SRC: C4.2, D5.2 (A), L1.1, Q3.3 (D)
SS_SD: D8.1, J4.P2 (CD/DAT3), R10.1, U2.4 (IO4)
TX: TP1.TP, U2.25 (TXD0/GPIO16)
USB_D+: D1.1 (I/O1_1), U2.14 (IO13)
USB_D-: D1.3 (I/O2_1), U2.13 (IO12)
VBAT: C2_BAT.1, MCP73831.3 (VBAT), Q1.3 (D), TP3.TP, U4.2 (CELL), U4.3 (VDD)
VBUS: C1_BAT.1, C4_USB.2, C5_USB.2, CHG_LED.A, D1.5 (VBUS), D2.2 (ANODE), MCP73831.4 (VIN), PFMP.050.1.2, Q1.1 (G), R1_PWRUSB.2, TP14.TP
VRTC: C8.1, C10_SUPERCAP.1, R_CAPACITOR.2, U3.14 (VBAT)
VUSB: J2.A4, J2.A9, J2.B4, J2.B9, PFMP.050.1.1

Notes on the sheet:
USB C connector & ESD protection
LDO Voltage Regulator
SD Card
ESP32 C6
Display Type Selector
E-Paper Drive Circuit
Li-Po Battery Charging Controller
E-Paper Display Header
EPD Power
Environmental Sensor BME688
Voltage Supervisor + Reset & Boot / IO Button
Battery Charge Level
RTC Module DS3231SN
Test Pads
Qwiic / Stemma QT
SPI ESD Protection Lines
External NOR Flash 64MB
drawn by: Alexia Mocanu
OpenBook Schematic

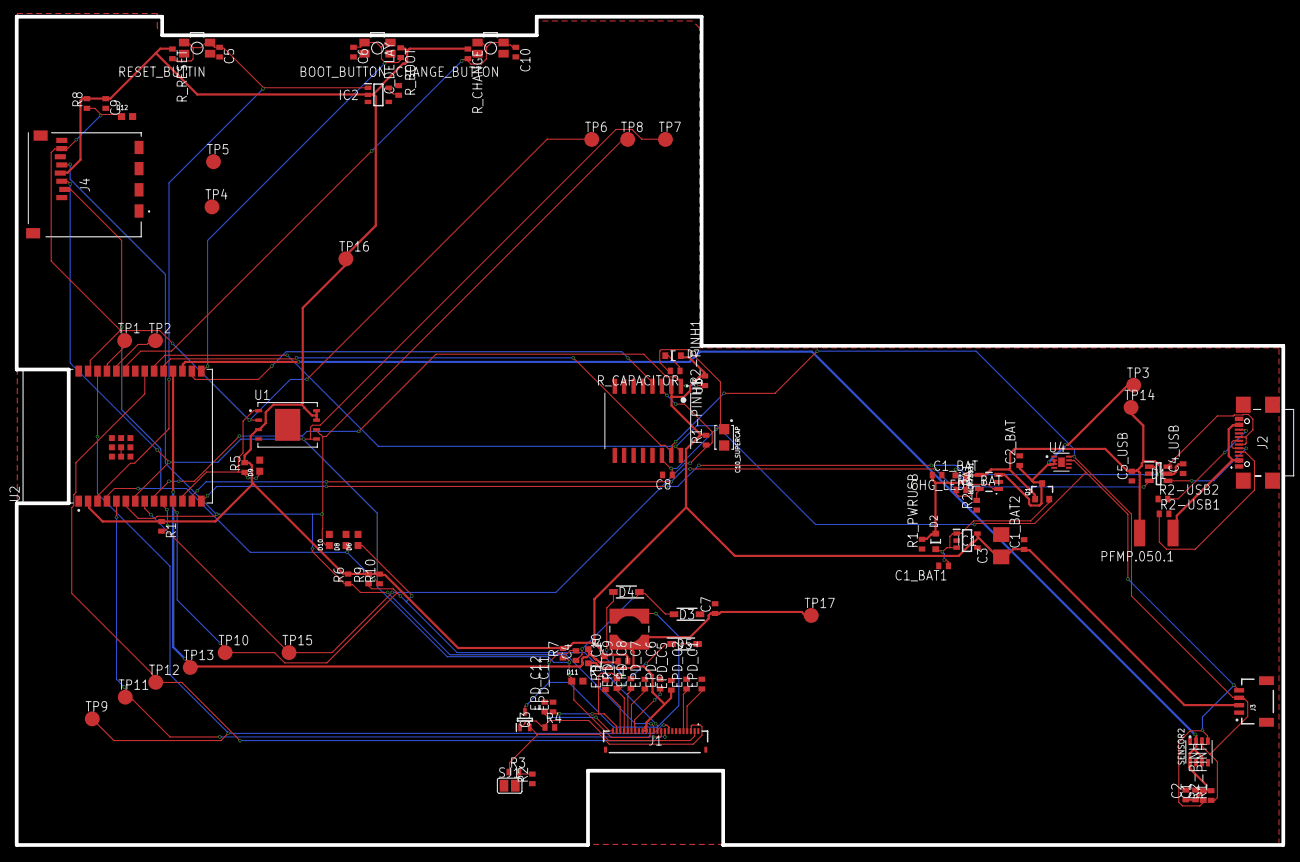
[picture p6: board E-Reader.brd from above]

Board: 2 copper layers, 170.5 x 111.5 mm, 103 parts (0 on the bottom side), 55 nets.

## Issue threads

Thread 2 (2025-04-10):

Display and battery models missing

biancapopescu0411, 2025-04-10:
You have to draw the display and battery 3d models and put them in the case as well.

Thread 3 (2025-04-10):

Case missing

biancapopescu0411, 2025-04-10:
You should download the case from the link on ocw and put the 3d PCB inside, along with the display and battery.

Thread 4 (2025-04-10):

BOM incomplete

biancapopescu0411, 2025-04-10:
The BOM in the README file is incomplete, you should add the missing component links.

Closed 2025-04-16.

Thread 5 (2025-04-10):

Names not on SilkScreen layer

biancapopescu0411, 2025-04-10:
The names in the PCB are not on the correct layer, you should change them. I personally took each one of them and changed the layer from the properties.

Closed 2025-04-16.

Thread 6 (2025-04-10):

PCB errors

biancapopescu0411, 2025-04-10:
There are multiple PCB errors, including some air wires and one overlap. Try re-routing and moving some components around.

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

Closed 2025-04-16.

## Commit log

2025-04-06 Update README.md
    Added BOM
2025-04-16 Resolved Issues
    [E-Reader.brd, E-Reader.sch, OpenBook Enclosure.f3d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]

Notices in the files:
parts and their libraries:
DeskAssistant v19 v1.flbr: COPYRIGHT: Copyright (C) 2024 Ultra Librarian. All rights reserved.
